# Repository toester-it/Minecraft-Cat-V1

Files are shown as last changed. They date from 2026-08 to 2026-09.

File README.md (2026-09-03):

# Minecraft-Cat-V1
Code (Joystick transmitter &amp; Cat reciever) + 3D Models (Cat parts)
TinkerCAD: https://www.tinkercad.com/things/lH2LceW6PMJ-minecraft-cat-v1

.Video links: 
- https://www.instagram.com/p/DZ3h2ahhazg/ (pt 1)
- https://www.instagram.com/p/Db1e2bLPgKe/ (pt 2)
            
# Preface
The legs and the inner mechanism might look a bit odd, but I designed it this way so that it reduces the need for too many servos. Since it doesn't use that many servos, it's ability to move is quite limited compared to other quadruped robots, but Minecraft cats have relatively simple walking animations. 
It can walk forward + backward, along with turning and a special trick (you can edit it to be whatever you want that trick to be!)

# Recommendations
1.  This cat uses around 7 Motors in total. You could use SG90's for the servos connected to the legs, but I really recommend using atleast 1 MG90 for the Rack & Pinion. The rack and Pinion handles a lot of weight (lifting the legs up and pushing the body up) and an SG90 might not provide enough torque or the inner plastic gears will strip. 
  Personally, I used MG90 for the whole thing
2.  Use a PCA9685 (servo driver) for all the servos. Originally, I didn't intend to use one and I saw my legs were glitching a lot (some would move to random angles spontaneously), but after using a PCA9685, it removed that issue and helped the servos move more smoothly.
3.  Please be careful to not short circuit :,) I don't have a PCB designed for this (yet)
4.  Everything is meant to be put together with M2 screws (8mm), except for the servos & the rack and pinion, use the screws that come with the servos.

# Final Notes
I don't have any set ideas on where to screw the PCA9685 and the ESP32 into. The butt, infront of the rack, and head have space for extra components but it's also important to keep in mind the center of gravity so this doesn't tip over. 

V1 was to mainly see how the cat would walk since that was my biggest worry, I didn't see a lot of guides on making cheap 4 legged robots (especially ones that move like a Minecraft cat) so it was a big struggle to design this. I'm not a robotics, mechatronics, electrical, or mechanical student. 

The body and head might not attach correctly or it'll tip over due to uneven weight distribution, I don't know yet. I don't have the money or time to print them out currently :P

If you have any tips or advice, please let me know! I really want to improve this into a real functioning Minecraft cat.

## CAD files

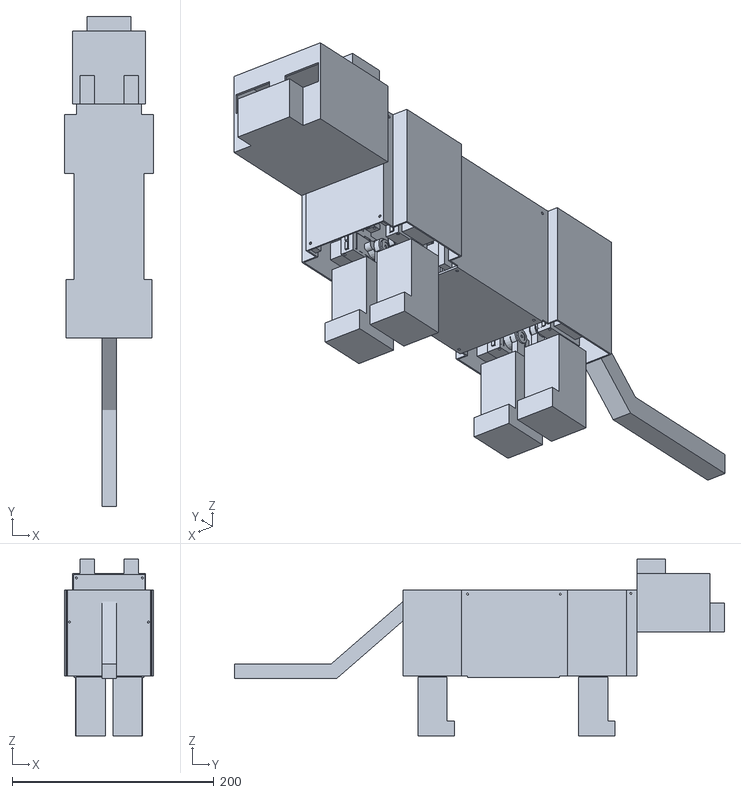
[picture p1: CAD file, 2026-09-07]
09_06 Minecraft Cat V.1.stl
88.2 x 486.2 x 175.5

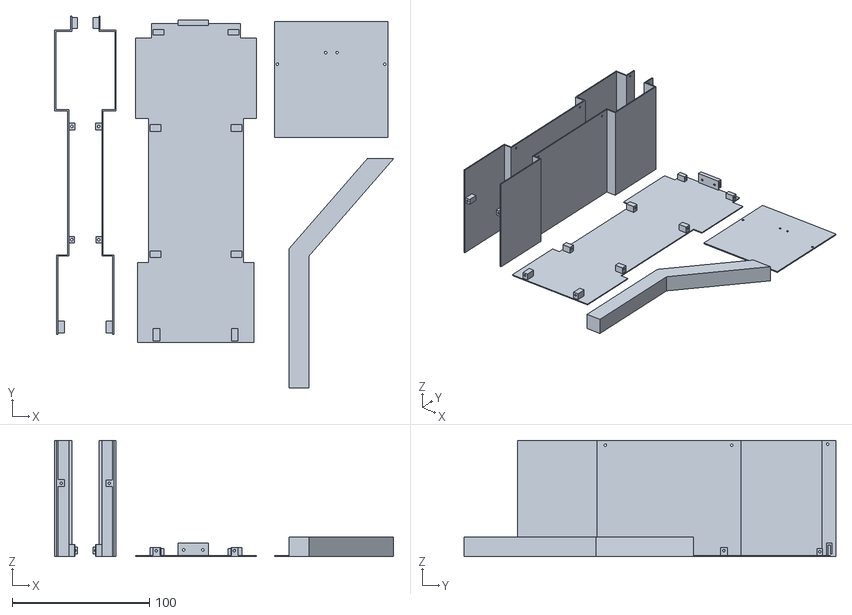
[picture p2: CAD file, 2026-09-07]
Minecraft Cat 3D Parts/Tails, sides, back, & top panel.stl
247.2 x 271.1 x 84.8

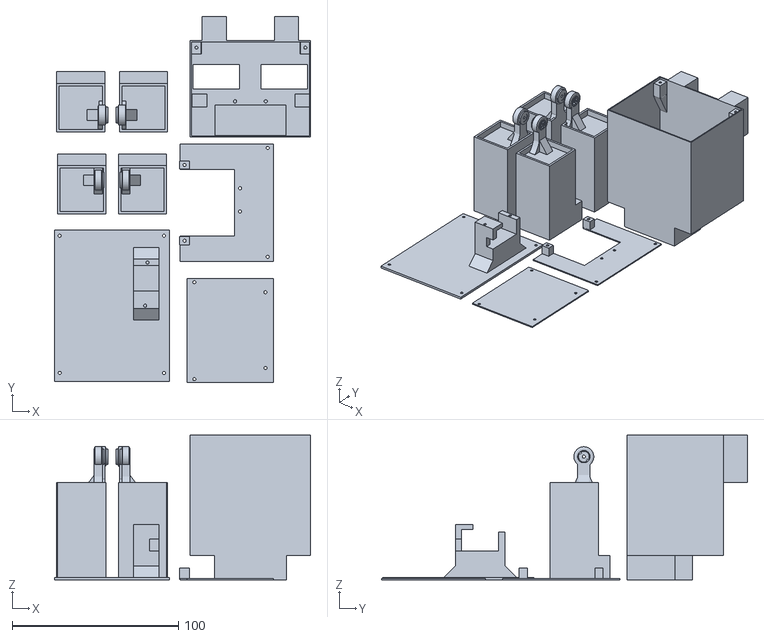
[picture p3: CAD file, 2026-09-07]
Minecraft Cat 3D Parts/Legs, head, and lower body panel.stl
154.2 x 220.2 x 87.0

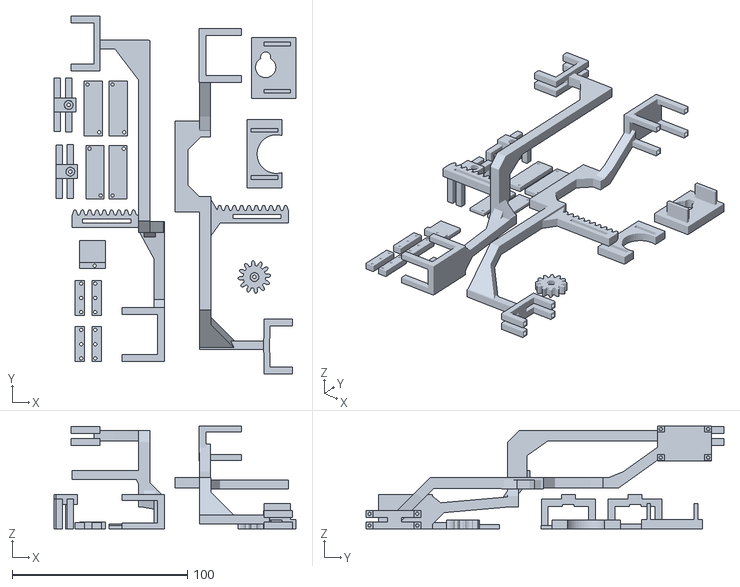
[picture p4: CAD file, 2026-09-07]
Minecraft Cat 3D Parts/Chassis & small parts.stl
138.0 x 204.1 x 58.7

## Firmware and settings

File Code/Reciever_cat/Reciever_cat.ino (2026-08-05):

#include <esp_now.h>
#include <WiFi.h>
#include <esp_wifi.h>
#include <Adafruit_PWMServoDriver.h>

typedef struct struct_message {
  int16_t x;            // -1000 to +1000
  int16_t y;            // -1000 to +1000
  bool buttonPressed;   // Switch/button state
} struct_message;

struct_message receivedData;

//PCA9685 setup
#define PCA9685_ADDRESS 0x40
Adafruit_PWMServoDriver pwm = Adafruit_PWMServoDriver(PCA9685_ADDRESS);

// Servo channels according to the PCA9685
#define SERVO_1_CH 0  // Front Right
#define SERVO_2_CH 1  // Front Left
#define SERVO_3_CH 2  // Rack and Pinion
#define SERVO_4_CH 3  // Back Right
#define SERVO_5_CH 4  // Back Left
#define SERVO_6_CH 5  // Left Rotator
#define SERVO_7_CH 6  // Right Rotator

// Servo pulse width constants
#define SERVO_MIN_PULSE 500   // µs for 0 degrees
#define SERVO_MAX_PULSE 2400  // µs for 180 degrees

// Track current angles
int currentAngles[7] = {90, 90, 90, 90, 100, 90, 90};

// Flags
volatile bool turnLeftFlag = false;
volatile bool turnRightFlag = false;
volatile bool walkForwardFlag = false;
volatile bool walkBackwardFlag = false;
volatile bool buttonPressedFlag = false;  // Button state from transmitter

bool isWalking = false;
bool isTurning = false;
bool leftTurnInitialized = false;
bool rightTurnInitialized = false;
bool isButtonActionRunning = false;  // Track if button action is currently running

// Set servo angle
void setServoAngle(uint8_t channel, int angle) {
  if (angle < 0) angle = 0;
  if (angle > 180) angle = 180;
  uint16_t pulse = map(angle, 0, 180, SERVO_MIN_PULSE, SERVO_MAX_PULSE);
  pwm.writeMicroseconds(channel, pulse);
}

// GET / UPDATE CURRENT ANGLE
int getCurrentAngle(uint8_t channel) {
  return currentAngles[channel];
}

void updateCurrentAngle(uint8_t channel, int angle) {
  currentAngles[channel] = angle;
}

// ESP-NOW CALLBACK: DATA RECEIVED
void onReceive(const esp_now_recv_info_t *recv_info, const uint8_t *data, int len) {
  memcpy(&receivedData, data, sizeof(receivedData));
  
  int x = receivedData.x;
  int y = receivedData.y;
  bool button = receivedData.buttonPressed;
  
  // ----- BUTTON STATE -----
  buttonPressedFlag = button;
  
  // ----- X-AXIS: TURN LEFT (x < -500) / TURN RIGHT (x > 500) -----
  if (x < -500) {
    turnLeftFlag = true;
    turnRightFlag = false;
  } else if (x > 500) {
    turnRightFlag = true;
    turnLeftFlag = false;
  } else {
    turnLeftFlag = false;
    turnRightFlag = false;
  }
  
  // ----- Y-AXIS: WALK FORWARD (y > 500) / WALK BACKWARD (y < -500) -----
  if (y > 500) {
    walkForwardFlag = true;
    walkBackwardFlag = false;
  } else if (y < -500) {
    walkBackwardFlag = true;
    walkForwardFlag = false;
  } else {
    walkForwardFlag = false;
    walkBackwardFlag = false;
  }
}

// BUTTON ACTION
void performButtonAction() {
  if (!buttonPressedFlag) {
    // Button was released - exit and reset to idle
    if (isButtonActionRunning) {
      isButtonActionRunning = false;
      resetToIdle();
    }
    return;
  }
  
  if (!isButtonActionRunning) {
    isButtonActionRunning = true;
    isWalking = false;
    isTurning = false;
    leftTurnInitialized = false;
    rightTurnInitialized = false;
    Serial.println("BUTTON HELD - Running reset sequence");
  }
  
  //BUTTON SEQUENCE
  setServoAngle(SERVO_6_CH, 90);
  updateCurrentAngle(SERVO_6_CH, 90);
  setServoAngle(SERVO_7_CH, 82);
  updateCurrentAngle(SERVO_7_CH, 82);
  slowMove(SERVO_3_CH, 90, 150);
  delay(20); 

  fastMoveTwoServos(SERVO_2_CH, 140, SERVO_1_CH, 40, 300);
  delay(20); 
  
}

// RIGHT TURN SETUP 
void rightTurnSetup() {
  Serial.println("RIGHT TURN SETUP - Running once");
  
  setServoAngle(SERVO_1_CH, 90);
  updateCurrentAngle(SERVO_1_CH, 90);
  setServoAngle(SERVO_2_CH, 90);
  updateCurrentAngle(SERVO_2_CH, 90);
  setServoAngle(SERVO_4_CH, 90);
  updateCurrentAngle(SERVO_4_CH, 90);
  setServoAngle(SERVO_5_CH, 100);
  updateCurrentAngle(SERVO_5_CH, 100);
  
  fastMoveSingleServo(SERVO_3_CH, 65, 100);
  delay(20);
  fastMoveSingleServo(SERVO_6_CH, 40, 100);
  delay(20);
  fastMoveSingleServo(SERVO_7_CH, 32, 100);
  delay(20);
  
  rightTurnInitialized = true;
}

// RIGHT TURN LOOP
void rightTurnLoop() {
  // Lock idle servos
  setServoAngle(SERVO_1_CH, 90);
  updateCurrentAngle(SERVO_1_CH, 90);
  setServoAngle(SERVO_4_CH, 90);
  updateCurrentAngle(SERVO_4_CH, 90);
  setServoAngle(SERVO_5_CH, 100);
  updateCurrentAngle(SERVO_5_CH, 100);

  fastMoveSingleServo(SERVO_2_CH, 115, 100);  
  delay(20);
  
  fastMoveSingleServo(SERVO_3_CH, 125, 100);
  delay(20);
  
  fastMoveSingleServo(SERVO_2_CH, 55, 100); 
  delay(20);
  
  fastMoveSingleServo(SERVO_3_CH, 65, 100);
  delay(20);
}

// LEFT TURN SETUP
void leftTurnSetup() {
  Serial.println("LEFT TURN SETUP - Running once");
  
  setServoAngle(SERVO_1_CH, 90);
  updateCurrentAngle(SERVO_1_CH, 90);
  setServoAngle(SERVO_2_CH, 90);
  updateCurrentAngle(SERVO_2_CH, 90);
  setServoAngle(SERVO_4_CH, 90);
  updateCurrentAngle(SERVO_4_CH, 90);
  setServoAngle(SERVO_5_CH, 100);
  updateCurrentAngle(SERVO_5_CH, 100);
  
  fastMoveSingleServo(SERVO_3_CH, 125, 100);
  delay(20);
  fastMoveSingleServo(SERVO_7_CH, 132, 100);
  delay(20);
  fastMoveSingleServo(SERVO_6_CH, 140, 100);
  delay(20);
  
  leftTurnInitialized = true;
}

// LEFT TURN LOOP
void leftTurnLoop() {
  // Lock idle servos
  setServoAngle(SERVO_2_CH, 90);
  updateCurrentAngle(SERVO_2_CH, 90);
  setServoAngle(SERVO_4_CH, 90);
  updateCurrentAngle(SERVO_4_CH, 90);
  setServoAngle(SERVO_5_CH, 100);
  updateCurrentAngle(SERVO_5_CH, 100);

  fastMoveSingleServo(SERVO_1_CH, 115, 100); 
  delay(20);
  
  fastMoveSingleServo(SERVO_3_CH, 125, 100);
  delay(20);
  
  fastMoveSingleServo(SERVO_1_CH, 55, 100);  
  delay(20);
  
  fastMoveSingleServo(SERVO_3_CH, 65, 100);
  delay(20);
}

// WALK FORWARD
void walkForward() {
  if (!isWalking) {
    isWalking = true;
    isTurning = false;
    Serial.println("Walking FORWARD (continuous)");
  }
  
  leftTurnInitialized = false;
  rightTurnInitialized = false;
  
  setServoAngle(SERVO_6_CH, 90);
  updateCurrentAngle(SERVO_6_CH, 90);
  setServoAngle(SERVO_7_CH, 82);
  updateCurrentAngle(SERVO_7_CH, 82);
  
  // Complete one walking cycle
  slowMove(SERVO_3_CH, 125, 150); // R&P drops
  delay(20); 

  fastMoveTwoServos(SERVO_2_CH, 70, SERVO_4_CH, 110, 300);
  delay(20);

  fastMoveTwoServos(SERVO_1_CH, 70, SERVO_5_CH, 120, 300);
  delay(20);
  
  slowMove(SERVO_3_CH, 65, 150);
  delay(20);

  fastMoveTwoServos(SERVO_2_CH, 110, SERVO_4_CH, 70, 300);
  delay(20); 

  fastMoveTwoServos(SERVO_1_CH, 110, SERVO_5_CH, 80, 300);
  delay(20); 
}

// WALK BACKWARD
void walkBackward() {
  if (!isWalking) {
    isWalking = true;
    isTurning = false;
    Serial.println("Walking BACKWARD (continuous)");
  }
  
  leftTurnInitialized = false;
  rightTurnInitialized = false;
  
  setServoAngle(SERVO_6_CH, 90);
  updateCurrentAngle(SERVO_6_CH, 90);
  setServoAngle(SERVO_7_CH, 82);
  updateCurrentAngle(SERVO_7_CH, 82);
  
  fastMoveSingleServo(SERVO_3_CH, 75, 150);
  delay(20);
  fastMoveTwoServos(SERVO_2_CH, 70, SERVO_4_CH, 110, 300);
  delay(20);
  fastMoveTwoServos(SERVO_1_CH, 70, SERVO_5_CH, 120, 300);
  delay(20);
  fastMoveSingleServo(SERVO_3_CH, 115, 150);
  delay(20);
  fastMoveTwoServos(SERVO_2_CH, 110, SERVO_4_CH, 70, 300);
  delay(20);
  fastMoveTwoServos(SERVO_1_CH, 110, SERVO_5_CH, 80, 300);
  delay(20);
}

// RESET TO IDLE
void resetToIdle() {
  isWalking = false;
  isTurning = false;
  isButtonActionRunning = false;
  leftTurnInitialized = false;
  rightTurnInitialized = false;
  Serial.println("Stopped - returning to idle");
  
  fastMoveSingleServo(SERVO_1_CH, 90, 300);
  fastMoveSingleServo(SERVO_2_CH, 90, 300);
  fastMoveSingleServo(SERVO_3_CH, 93, 300);
  fastMoveSingleServo(SERVO_4_CH, 90, 300);
  fastMoveSingleServo(SERVO_5_CH, 100, 300);
  fastMoveSingleServo(SERVO_6_CH, 90, 300);
  fastMoveSingleServo(SERVO_7_CH, 82, 300);
}

// SERVO MOVEMENT FUNCTIONS
void slowMove(uint8_t channel, int targetAngle, int duration) {
  int currentAngle = getCurrentAngle(channel);
  int totalDegrees = abs(targetAngle - currentAngle);
  if (totalDegrees == 0) return;
  
  int delayPerDegree = duration / totalDegrees;
  if (delayPerDegree < 15) delayPerDegree = 15;
  
  if (currentAngle < targetAngle) {
    for (int angle = currentAngle; angle <= targetAngle; angle++) {
      setServoAngle(channel, angle);
      updateCurrentAngle(channel, angle);
      delay(delayPerDegree);
    }
  } else {
    for (int angle = currentAngle; angle >= targetAngle; angle--) {
      setServoAngle(channel, angle);
      updateCurrentAngle(channel, angle);
      delay(delayPerDegree);
    }
  }
  
  setServoAngle(channel, targetAngle);
  updateCurrentAngle(channel, targetAngle);
  delay(15);
}

void fastMoveSingleServo(uint8_t channel, int targetAngle, int duration) {
  int currentAngle = getCurrentAngle(channel);
  int totalDegrees = abs(targetAngle - currentAngle);
  if (totalDegrees == 0) return;
  
  int stepSize = 3;
  int steps = totalDegrees / stepSize;
  if (steps == 0) steps = 1;
  
  int delayPerStep = duration / steps;
  if (delayPerStep < 5) delayPerStep = 5;
  
  int direction = (currentAngle < targetAngle) ? 1 : -1;
  
  for (int step = 1; step <= steps; step++) {
    int newAngle = currentAngle + (direction * step * stepSize);
    if (step == steps) newAngle = targetAngle;
    setServoAngle(channel, newAngle);
    updateCurrentAngle(channel, newAngle);
    delay(delayPerStep);
  }
  
  setServoAngle(channel, targetAngle);
  updateCurrentAngle(channel, targetAngle);
  delay(10);
}

void fastMoveTwoServos(uint8_t channelA, int targetA, uint8_t channelB, int targetB, int duration) {
  int currentA = getCurrentAngle(channelA);
  int currentB = getCurrentAngle(channelB);
  
  int totalDegreesA = abs(targetA - currentA);
  int totalDegreesB = abs(targetB - currentB);
  
  int stepSize = 3;
  int stepsA = totalDegreesA / stepSize;
  int stepsB = totalDegreesB / stepSize;
  int maxSteps = max(stepsA, stepsB);
  if (maxSteps == 0) return;
  
  int delayPerStep = duration / maxSteps;
  if (delayPerStep < 5) delayPerStep = 5;
  
  int dirA = (currentA < targetA) ? 1 : -1;
  int dirB = (currentB < targetB) ? 1 : -1;
  
  for (int step = 0; step <= maxSteps; step++) {
    if (stepsA > 0) {
      int angleA = currentA + (dirA * step * totalDegreesA / maxSteps);
      setServoAngle(channelA, angleA);
      updateCurrentAngle(channelA, angleA);
    }
    if (stepsB > 0) {
      int angleB = currentB + (dirB * step * totalDegreesB / maxSteps);
      setServoAngle(channelB, angleB);
      updateCurrentAngle(channelB, angleB);
    }
    delay(delayPerStep);
  }
  
  setServoAngle(channelA, targetA);
  updateCurrentAngle(channelA, targetA);
  setServoAngle(channelB, targetB);
  updateCurrentAngle(channelB, targetB);
  delay(10);
}

// SETUP
void setup() {
  Serial.begin(115200);
  Serial.println("Receiver starting with PCA9685...");
  
  //INITIALIZE PCA9685
  pwm.begin();
  pwm.setOscillatorFrequency(27000000);
  pwm.setPWMFreq(50);
  delay(10);
  
  //SET INITIAL POSITIONS
  setServoAngle(SERVO_1_CH, 90);
  currentAngles[SERVO_1_CH] = 90;
  delay(50);
  setServoAngle(SERVO_2_CH, 90);
  currentAngles[SERVO_2_CH] = 90;
  delay(50);
  setServoAngle(SERVO_3_CH, 93);
  currentAngles[SERVO_3_CH] = 93;
  delay(50);
  setServoAngle(SERVO_4_CH, 90);
  currentAngles[SERVO_4_CH] = 90;
  delay(50);
  setServoAngle(SERVO_5_CH, 100);
  currentAngles[SERVO_5_CH] = 100;
  delay(50);
  setServoAngle(SERVO_6_CH, 90);
  currentAngles[SERVO_6_CH] = 90;
  delay(50);
  setServoAngle(SERVO_7_CH, 82);
  currentAngles[SERVO_7_CH] = 82; //Ideally, have all of these angles at 90 (in idle position too)
  //If you have to offset some angles, offset them for every movement!
  
  delay(5000);
  
  //ESP-NOW INIT
  WiFi.mode(WIFI_STA);
  esp_wifi_set_promiscuous(true);
  esp_wifi_set_channel(1, WIFI_SECOND_CHAN_NONE);
  esp_wifi_set_promiscuous(false);
  
  if (esp_now_init() != ESP_OK) {
    Serial.println("ESP-NOW init failed");
    while (1);
  }
  
  esp_now_register_recv_cb(onReceive);
  Serial.println("Receiver ready!");
}

// MAIN LOOP
void loop() {
  // ----- TURN LEFT (In order of priority) -----
  if (turnLeftFlag) {
    isTurning = true;
    isWalking = false;
    isButtonActionRunning = false; 
    
    if (!leftTurnInitialized) {
      leftTurnSetup();
    }
    
    leftTurnLoop();
  } 
  // ----- TURN RIGHT -----
  else if (turnRightFlag) {
    isTurning = true;
    isWalking = false;
    isButtonActionRunning = false;
    
    if (!rightTurnInitialized) {
      rightTurnSetup();
    }
    
    rightTurnLoop();
  }
  // ----- WALK FORWARD -----
  else if (walkForwardFlag) {
    isWalking = true;
    isTurning = false;
    isButtonActionRunning = false;
    walkForward();
  } 
  // ----- WALK BACKWARD -----
  else if (walkBackwardFlag) {
    isWalking = true;
    isTurning = false;
    isButtonActionRunning = false;
    walkBackward();
  } 
  // ----- BUTTON ACTION (Only runs when joystick is centered) -----
  else if (buttonPressedFlag) {
    // Run button action - it will handle its own looping and exit when button released
    performButtonAction();
  }
  // ----- STOP -----
  else {
    if (isWalking || isTurning || isButtonActionRunning) {
      resetToIdle();
    }
    setServoAngle(SERVO_5_CH, 100);
    currentAngles[SERVO_5_CH] = 100;
    delay(10);
  }
  
  delay(10);
}

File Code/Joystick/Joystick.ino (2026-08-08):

#include <esp_now.h>
#include <WiFi.h>
#include <esp_wifi.h>

#define JOY_X_PIN 35  // joystick X (GPIO 35)
#define JOY_Y_PIN 34  // joystick Y (GPIO 34)
#define SWITCH_PIN 15 

// ----- MAC ADDRESS - REPLACE WITH YOUR RECEIVER'S MAC -----
uint8_t receiverAddress[] = { 0xAA, 0xAA, 0xAA, 0xAA, 0xAA, 0xAA }; //Don't delete the 0x

typedef struct struct_message {
  int16_t x;            // -1000 to 1000 range
  int16_t y;            // -1000 to 1000 range
  bool buttonPressed;   // Switch/button state
} struct_message;

struct_message myData;

void onSent(const wifi_tx_info_t *tx_info, esp_now_send_status_t status) {
  Serial.print("Send Status: ");
  Serial.println(status == ESP_NOW_SEND_SUCCESS ? "Success" : "Fail");
}

void setup() {
  Serial.begin(115200);

  // ----- SETUP SWITCH PIN -----
  pinMode(SWITCH_PIN, INPUT_PULLUP);

  WiFi.mode(WIFI_STA);
  WiFi.disconnect();

  esp_wifi_set_promiscuous(true);
  esp_wifi_set_channel(1, WIFI_SECOND_CHAN_NONE);
  esp_wifi_set_promiscuous(false);

  if (esp_now_init() != ESP_OK) {
    Serial.println("ESP-NOW init failed");
    while (1);
  }
  
  esp_now_register_send_cb(onSent);

  esp_now_peer_info_t peerInfo = {};
  memcpy(peerInfo.peer_addr, receiverAddress, 6);
  peerInfo.channel = 1;
  peerInfo.encrypt = false;

  if (esp_now_add_peer(&peerInfo) != ESP_OK) {
    Serial.println("Failed to add peer");
    while (1);
  }
  
  Serial.println("Transmitter ready!");
}

void loop() {
  int rawX = analogRead(JOY_X_PIN);
  int rawY = analogRead(JOY_Y_PIN);
  
  // Read switch state (LOW = pressed because of pull-up)
  bool switchPressed = (digitalRead(SWITCH_PIN) == LOW);

  // ----- PRINT DEBUG INFO -----
  Serial.print("Raw X: ");
  Serial.print(rawX);
  Serial.print(" | Raw Y: ");
  Serial.print(rawY);
  Serial.print(" | Switch: ");
  Serial.println(switchPressed ? "PRESSED" : "RELEASED");

  // ----- MAP JOYSTICK VALUES -----
  myData.x = map(rawX, 0, 4095, 1000, -1000);
  myData.y = map(rawY, 0, 4095, 1000, -1000);
  myData.buttonPressed = switchPressed;

  // ----- SEND DATA -----
  esp_err_t result = esp_now_send(receiverAddress, (uint8_t *)&myData, sizeof(myData));

  if (result != ESP_OK) {
    Serial.println("Send error");
  }

  delay(50);
}

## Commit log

2026-08-08 Create Tails, sides, back, and top pannel.stl
    [Tails, sides, back, and top pannel.stl]
2026-09-07 Add files via upload
    Fixed some issues & added new features
    [Chassis & small parts.stl, Legs, head, and lower body panel.stl, Tails, sides, back, & top panel.stl]
2026-09-07 Add files via upload
    Revamped the insides
    [09_06 Minecraft Cat V.1.stl]
